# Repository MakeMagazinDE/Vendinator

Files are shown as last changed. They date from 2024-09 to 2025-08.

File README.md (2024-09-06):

GitHub Logo

Maker Media GmbH

***

# Verkaufsautomat mit ESP

### Eigene Waren zu vertreiben, kann ganz schön aufwendig sein. Mit einem selbst gebauten Automaten geht das ganz einfach. Einmal eingestellt, übernimmt er die Transaktionen und meldet Verkäufe und Fehler ans Smartphone. Man muss sich nur gut überlegen, wie Hard- und Software zusammenspielen sollen. Dann lässt sich sogar im Schlaf Geld verdienen.

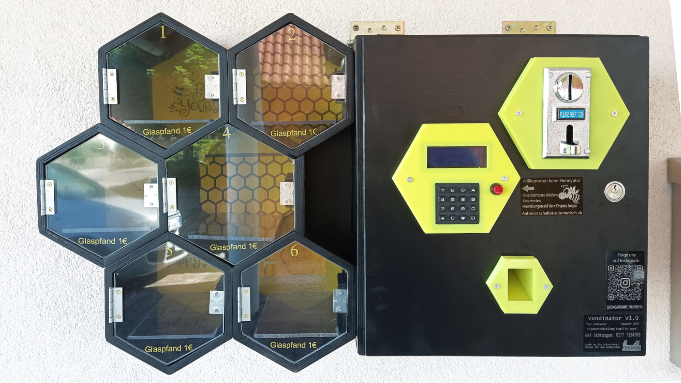
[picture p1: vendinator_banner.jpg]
Aufmacherbild aus dem Heft


Ergänzend zum Artikel in der Make 5/24 findet ihr hier die Sketches, Schaltpläne und Ablaufpläne.

Den vollständigen Artikel kann man in der **[Make-Ausgabe 5/24](https://www.heise.de/select/make/2024/5)** lesen.

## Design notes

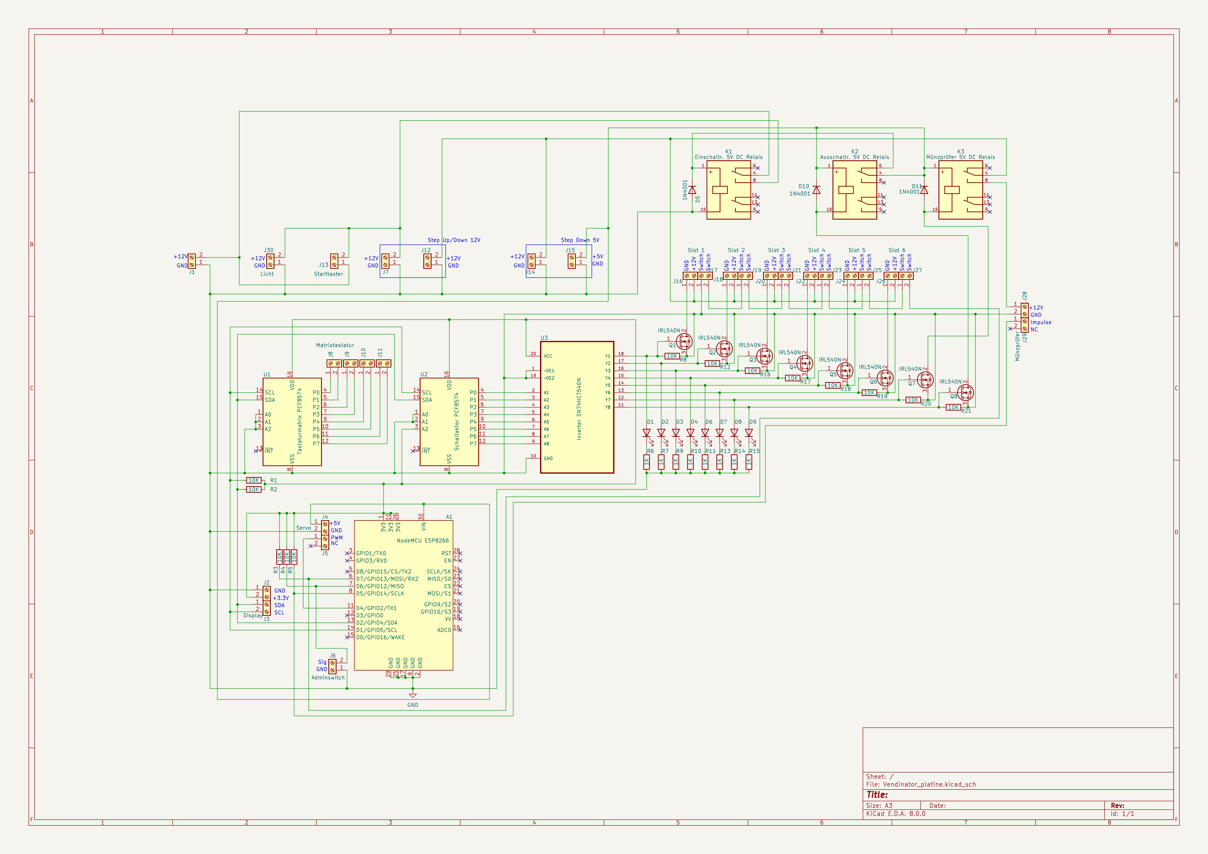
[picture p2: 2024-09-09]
Schaltplan/vendinator_schaltplan.jpg

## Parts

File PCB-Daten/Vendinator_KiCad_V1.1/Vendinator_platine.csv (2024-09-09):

# | Reference | Qty | Value | Footprint | DNP
1 | A1 | 1 | NodeMCU ESP8266 | Module:NodeMCU-LoLinV3
2 | D1 | 1 | LED grün | LED_THT:LED_D5.0mm
3 | D2, D3, D4, D5, D6, D7, D8 | 7 | LED | LED_THT:LED_D5.0mm
4 | D9, D10, D11 | 3 | 1N4001 | Diode_THT:D_DO-41_SOD81_P10.16mm_Horizontal
5 | J1 | 1 | Display | Connector_PinHeader_2.54mm:PinHeader_1x04_P2.54mm_Vertical
6 | J2 | 1 | Servo (Escrow) | Connector_PinSocket_2.54mm:PinSocket_1x03_P2.54mm_Vertical
7 | J3 | 1 | Adminswitch | Connector_Pin:Pin_D1.3mm_L11.0mm
8 | J4 | 1 | Matrixtastatur | Connector_PinSocket_2.54mm:PinSocket_1x08_P2.54mm_Vertical
9 | J5 | 1 | Münzprüfer | Connector_PinHeader_2.54mm:PinHeader_1x03_P2.54mm_Vertical
10 | J6 | 1 | Slot 1 | Connector_PinHeader_2.54mm:PinHeader_1x04_P2.54mm_Vertical
11 | J7 | 1 | Slot 2 | Connector_PinHeader_2.54mm:PinHeader_1x04_P2.54mm_Vertical
12 | J8 | 1 | Slot 3 | Connector_PinHeader_2.54mm:PinHeader_1x04_P2.54mm_Vertical
13 | J9 | 1 | Slot 4 | Connector_PinHeader_2.54mm:PinHeader_1x04_P2.54mm_Vertical
14 | J10 | 1 | Slot 5 | Connector_PinHeader_2.54mm:PinHeader_1x04_P2.54mm_Vertical
15 | J11 | 1 | Slot 6 | Connector_PinHeader_2.54mm:PinHeader_1x04_P2.54mm_Vertical
16 | J12 | 1 | Starttaster | Connector_PinHeader_2.54mm:PinHeader_1x02_P2.54mm_Vertical
17 | J13 | 1 | Batterie IN | Connector_PinHeader_2.54mm:PinHeader_1x02_P2.54mm_Vertical
18 | J14 | 1 | DC/DC 12V IN | Connector_PinHeader_2.54mm:PinHeader_1x02_P2.54mm_Vertical
19 | J15 | 1 | 12V DC/DC OUT | Connector_PinHeader_2.54mm:PinHeader_1x02_P2.54mm_Vertical
20 | J16 | 1 | 12V DC/DC IN | Connector_PinHeader_2.54mm:PinHeader_1x02_P2.54mm_Vertical
21 | J17 | 1 | 5V DC/DC OUT | Connector_PinHeader_2.54mm:PinHeader_1x02_P2.54mm_Vertical
22 | K1 | 1 | Münzprüfer 5V DC Relais | Relay_THT:Relay_DPDT_Finder_40.52
23 | K2 | 1 | Ausschaltr. 5V DC Relais | Relay_THT:Relay_DPDT_Finder_40.52
24 | K3 | 1 | Einschaltr. 5V DC Relais | Relay_THT:Relay_DPDT_Finder_40.52
25 | Q1, Q2, Q3, Q4, Q5, Q6, Q7, Q8 | 8 | IRL540N | Package_TO_SOT_THT:TO-220-3_Vertical
26 | R1, R2, R3, R4, R5, R6, R7, R8 | 8 | 1K | Resistor_THT:R_Axial_DIN0207_L6.3mm_D2.5mm_P10.16mm_Horizontal
27 | R9, R10, R11, R12, R13, R14, R15, R16, R17, R18, R19, R20, R21 | 13 | 10K | Resistor_THT:R_Axial_DIN0207_L6.3mm_D2.5mm_P10.16mm_Horizontal
28 | U1 | 1 | Tastaturmatrix PCF8574 | Package_DIP:DIP-16_W7.62mm_Socket_LongPads
29 | U2 | 1 | Schaltaktor PCF8574 | Package_DIP:DIP-16_W7.62mm_Socket_LongPads
30 | U3 | 1 | Inverter SN74HCT540N | Package_DIP:DIP-20_W7.62mm_Socket

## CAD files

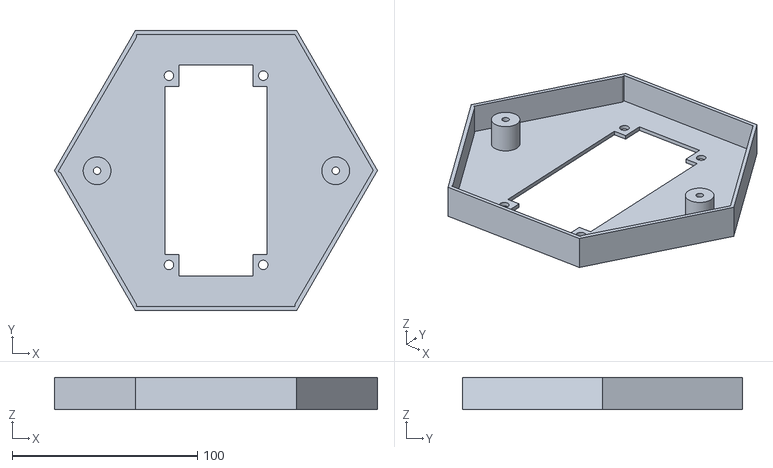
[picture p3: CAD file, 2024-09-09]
3D-Druckdaten/Wabe_Münzeinwurf.stl
174.5 x 151.1 x 17.5

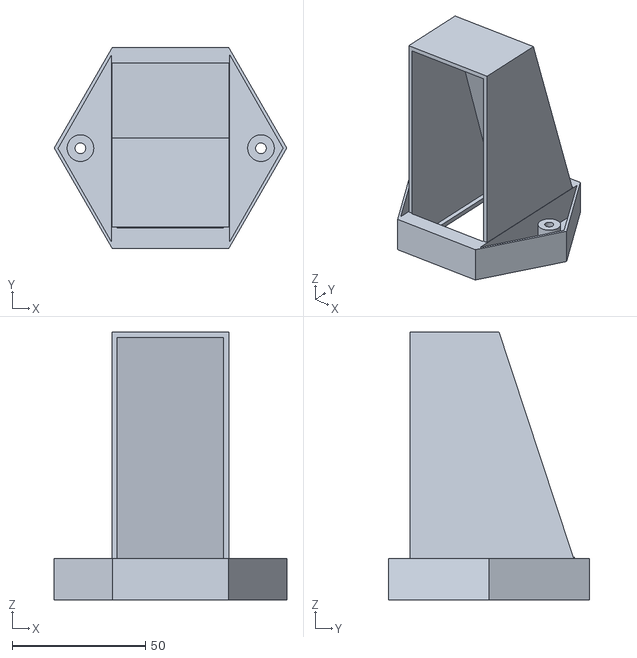
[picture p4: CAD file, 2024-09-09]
3D-Druckdaten/Geldrückgabe_Hauptteil.stl
87.2 x 75.6 x 100.5

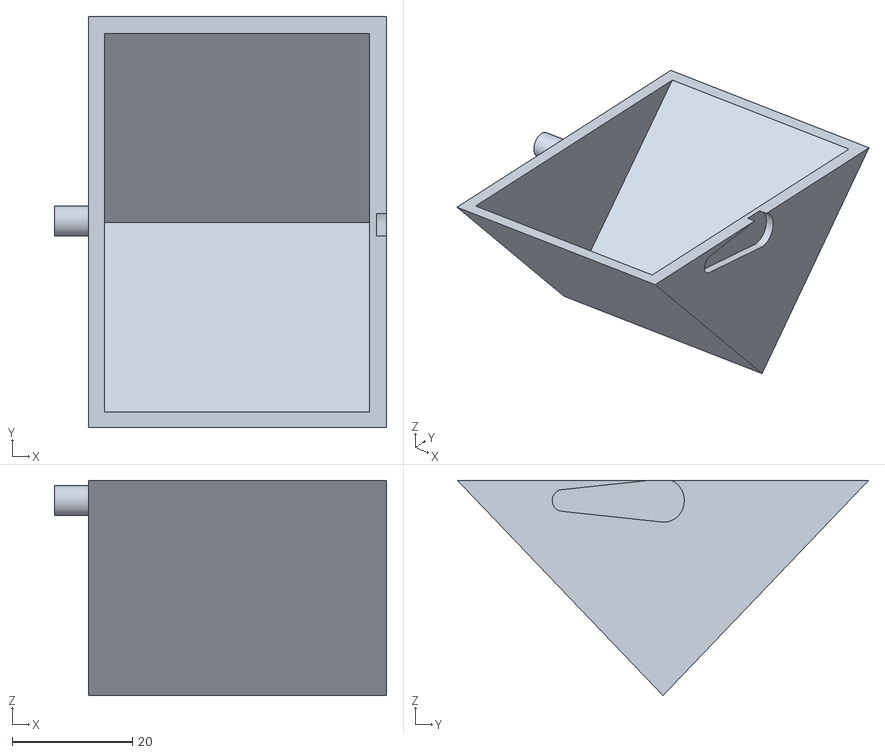
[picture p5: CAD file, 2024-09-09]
3D-Druckdaten/Münzweiche_Wippe.stl
55.3 x 68.5 x 35.9

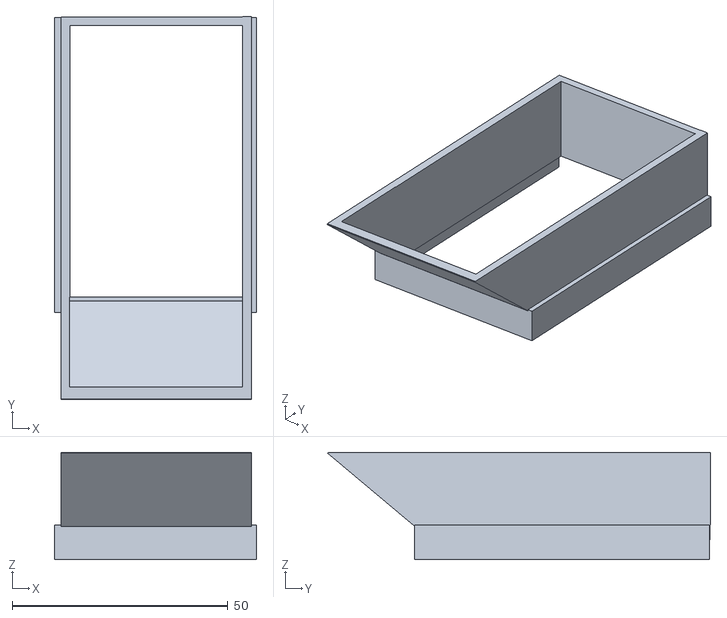
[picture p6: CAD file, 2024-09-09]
3D-Druckdaten/Geldrückgabe_Aufsatz.stl
46.8 x 88.7 x 24.8

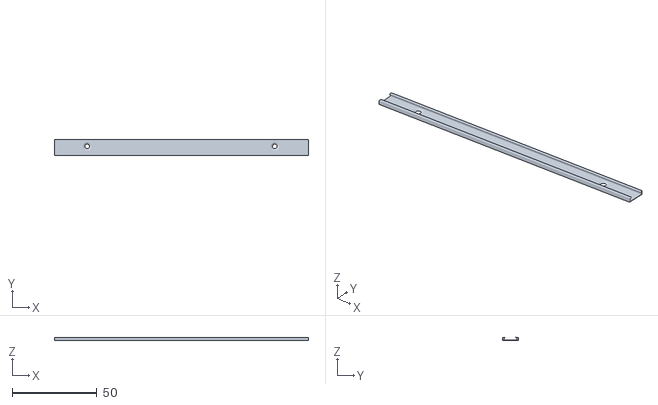
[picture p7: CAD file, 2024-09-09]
3D-Druckdaten/LEDStripe_Halter.stl
150.0 x 9.50 x 2.00

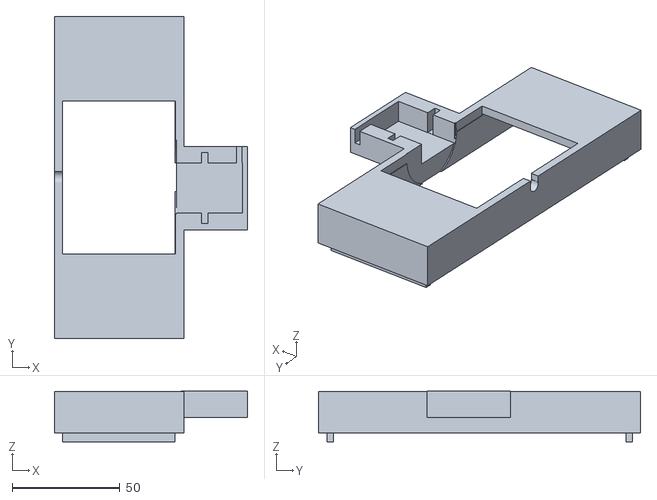
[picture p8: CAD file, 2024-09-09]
3D-Druckdaten/Münzweiche_Oberteil.stl
89.5 x 149.4 x 23.4

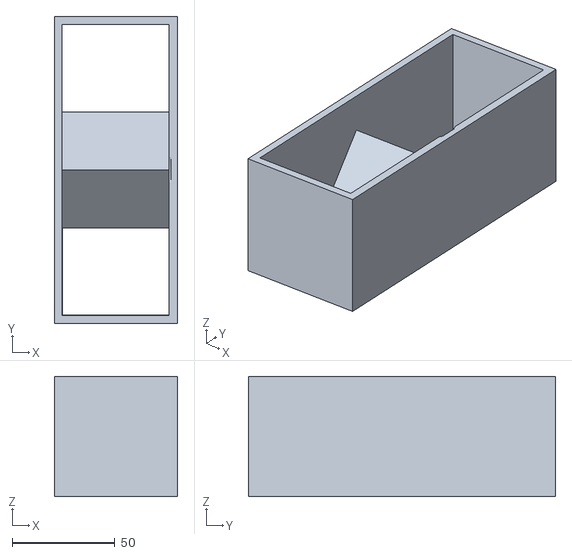
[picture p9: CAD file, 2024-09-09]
3D-Druckdaten/Münzweiche_Unterteil.stl
60.0 x 149.4 x 58.4

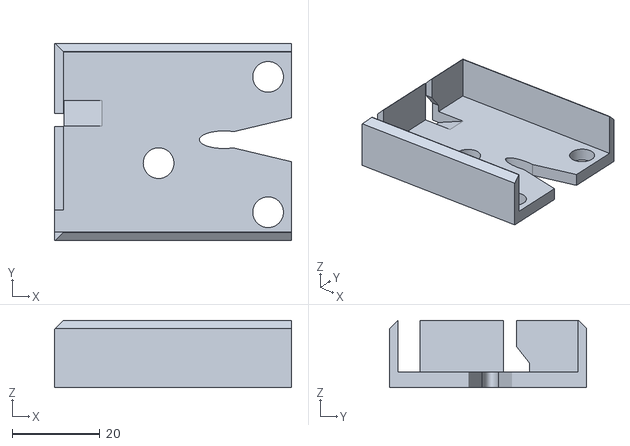
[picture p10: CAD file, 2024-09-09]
3D-Druckdaten/Schloss_Abstandshalter.stl
54.1 x 45.0 x 15.3

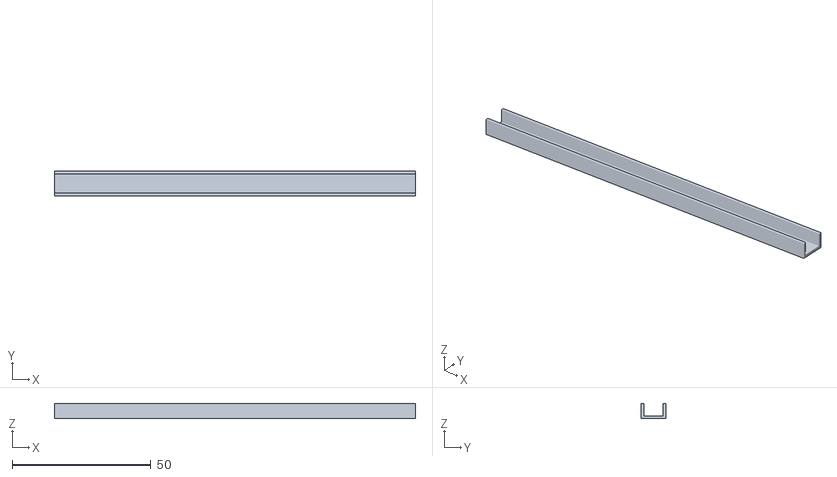
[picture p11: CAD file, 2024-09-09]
3D-Druckdaten/Kabelabdeckung.stl
130.0 x 9.00 x 5.50

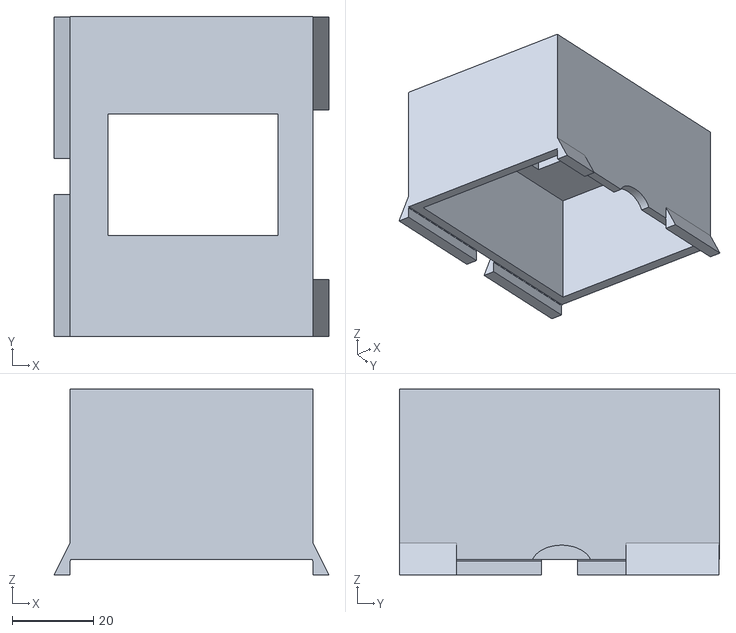
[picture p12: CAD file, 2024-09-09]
3D-Druckdaten/Münzweiche_Aufsatz.stl
67.8 x 79.0 x 45.8

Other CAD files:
3D-Druckdaten/Wabe_Bedienteil.stl

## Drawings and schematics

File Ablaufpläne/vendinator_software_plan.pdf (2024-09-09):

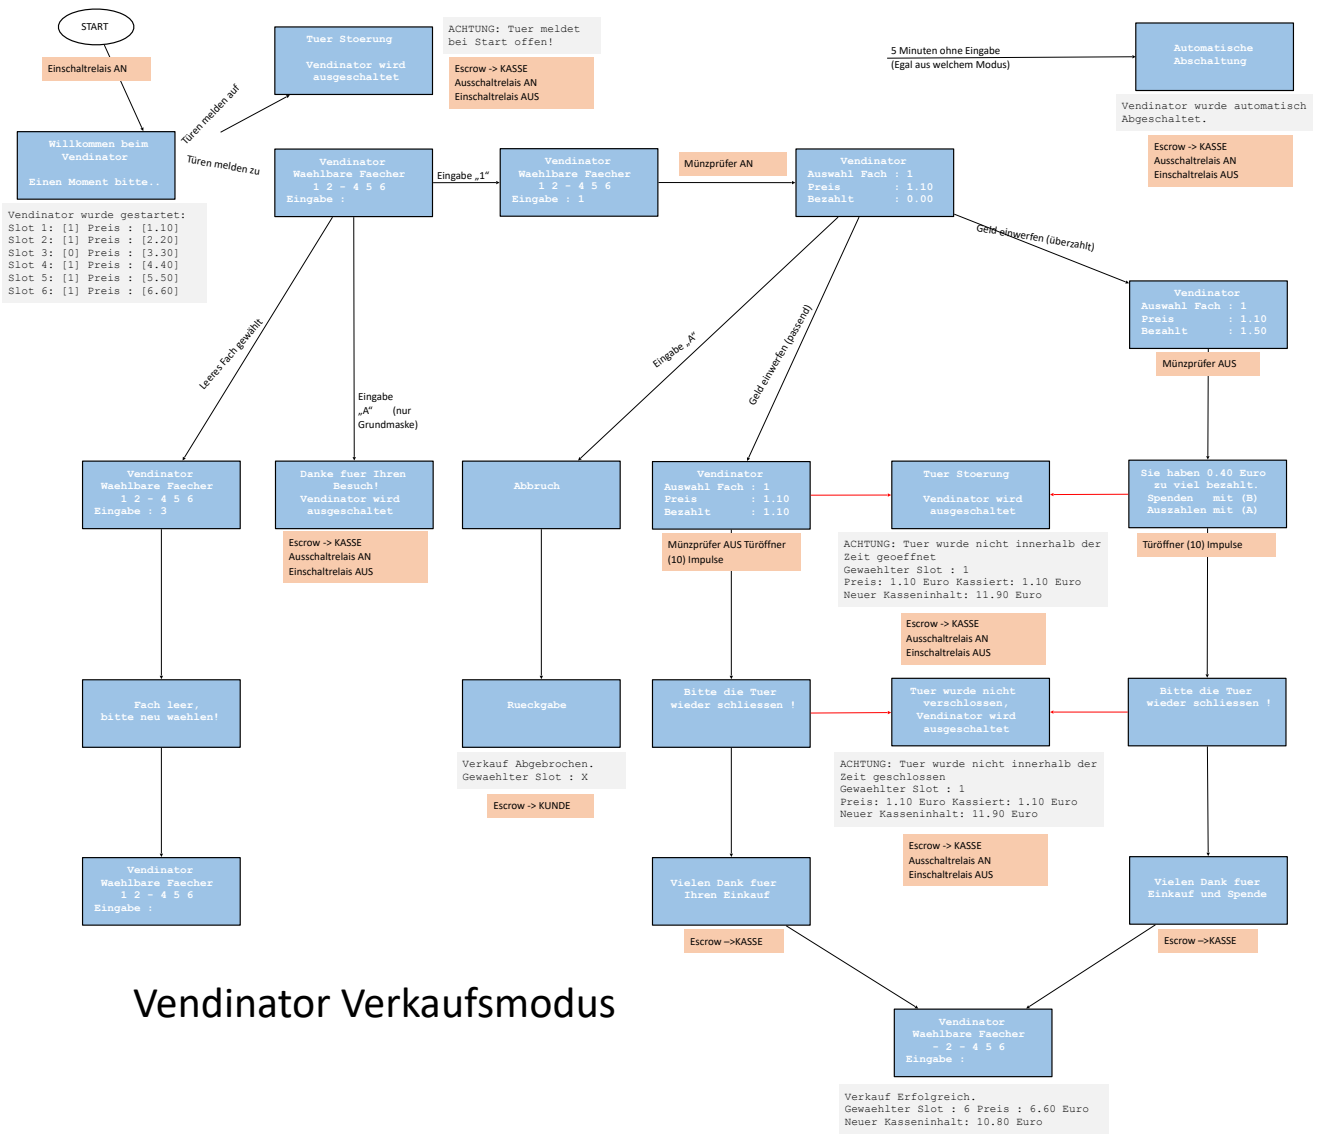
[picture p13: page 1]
Vendinator Waehlbare Faecher 1 2 - 4 5 6 Eingabe :; Vendinator Waehlbare Faecher 1 2 - 4 5 6 Eingabe : 1; Vendinator Auswahl Fach : 1; Preis; Bezahlt; Abbruch; Tuer Stoerung; Vendinator wird ausgeschaltet; Vendinator Waehlbare Faecher - 2 - 4 5 6 Eingabe :; Spenden; mit (B); Vendinator Verkaufsmodus; Willkommen beim Vendinator; START; Eingabe „1“; Eingabe „A“; Vendinator Waehlbare Faecher 1 2 - 4 5 6 Eingabe : 3; Eingabe; (nur; Grundmaske); Rueckgabe; Verkauf Abgebrochen. Gewaehlter Slot : X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

ACHTUNG: Tuer meldet
bei Start offen!

5 Minuten ohne Eingabe
(Egal aus welchem Modus)

Türen melden auf

Vendinator wurde automatisch
Abgeschaltet.

Türen melden zu

Einen Moment bitte..

Vendinator wurde gestartet:
Slot 1: [1] Preis : [1.10]
Slot 2: [1] Preis : [2.20]
Slot 3: [0] Preis : [3.30]
Slot 4: [1] Preis : [4.40]
Slot 5: [1] Preis : [5.50]
Slot 6: [1] Preis : [6.60]

Geld einwerfen (überzahlt)

Geld einwerfen (passend)

Leeres Fach gewählt

Danke fuer Ihren
Besuch!
Vendinator wird
ausgeschaltet

Sie haben 0.40 Euro
zu viel bezahlt.
Auszahlen mit (A)

ACHTUNG: Tuer wurde nicht innerhalb der
Zeit geoeffnet
Gewaehlter Slot : 1
Preis: 1.10 Euro Kassiert: 1.10 Euro
Neuer Kasseninhalt: 11.90 Euro

Münzprüfer AUS Türöffner
(10) Impulse

Bitte die Tuer
wieder schliessen !

Tuer wurde nicht
verschlossen,

Fach leer,
bitte neu waehlen!

Zeit geschlossen

Vielen Dank fuer
Ihren Einkauf

Einkauf und Spende

Verkauf Erfolgreich.
Gewaehlter Slot : 6 Preis : 6.60 Euro
Neuer Kasseninhalt: 10.80 Euro

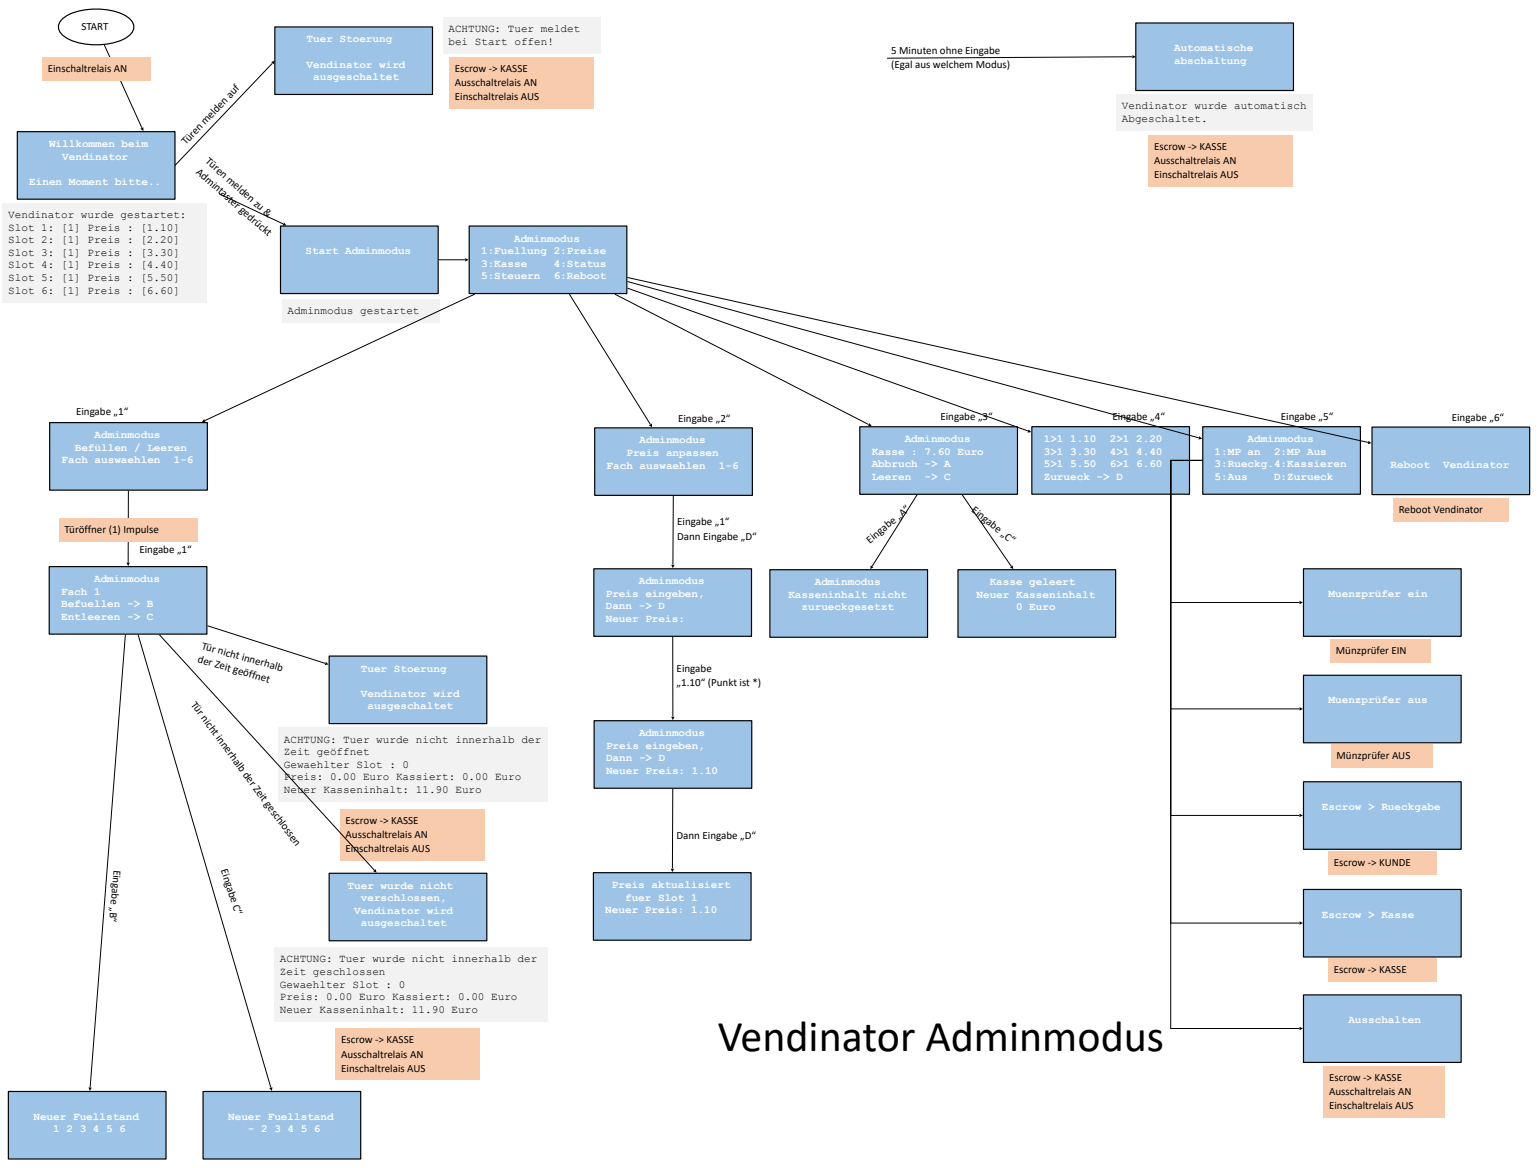
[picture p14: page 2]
Adminmodus 1:Fuellung 2:Preise; 3:Kasse; 4:Status; 5:Steuern 6:Reboot; Adminmodus Befüllen / Leeren Fach auswaehlen 1-6; Adminmodus Fach 1 Befuellen -> B Entleeren -> C; Adminmodus Preis anpassen Fach auswaehlen 1-6; Adminmodus Preis eingeben, Dann -> D Neuer Preis:; Adminmodus Preis eingeben, Dann -> D Neuer Preis: 1.10; Preis aktualisiert fuer Slot 1 Neuer Preis: 1.10; Adminmodus Kasse : 7.60 Euro Abbruch -> A Leeren -> C; Adminmodus Kasseninhalt nicht zurueckgesetzt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

ACHTUNG: Tuer meldet
bei Start offen!

5 Minuten ohne Eingabe
(Egal aus welchem Modus)

Türen melden auf

Vendinator wurde automatisch
Abgeschaltet.

Türen melden zu &

Einen Moment bitte..

Vendinator wurde gestartet:
Slot 1: [1] Preis : [1.10]
Slot 2: [1] Preis : [2.20]
Slot 3: [1] Preis : [3.30]
Slot 4: [1] Preis : [4.40]
Slot 5: [1] Preis : [5.50]
Slot 6: [1] Preis : [6.60]

Adminmodus
1:MP an 2:MP Aus
3:Rueckg.4:Kassieren

Eingabe „1“ Dann Eingabe „D“ | Reboot Vendinator

Türöffner (1) Impulse

Tür nicht innerhalb

der Zeit geöffnet

Tür nicht innerhalb der Zeit geschlossen

ACHTUNG: Tuer wurde nicht innerhalb der
Zeit geöffnet
Gewaehlter Slot : 0
Preis: 0.00 Euro Kassiert: 0.00 Euro
Neuer Kasseninhalt: 11.90 Euro

Tuer wurde nicht
verschlossen,
Vendinator wird
ausgeschaltet

Zeit geschlossen

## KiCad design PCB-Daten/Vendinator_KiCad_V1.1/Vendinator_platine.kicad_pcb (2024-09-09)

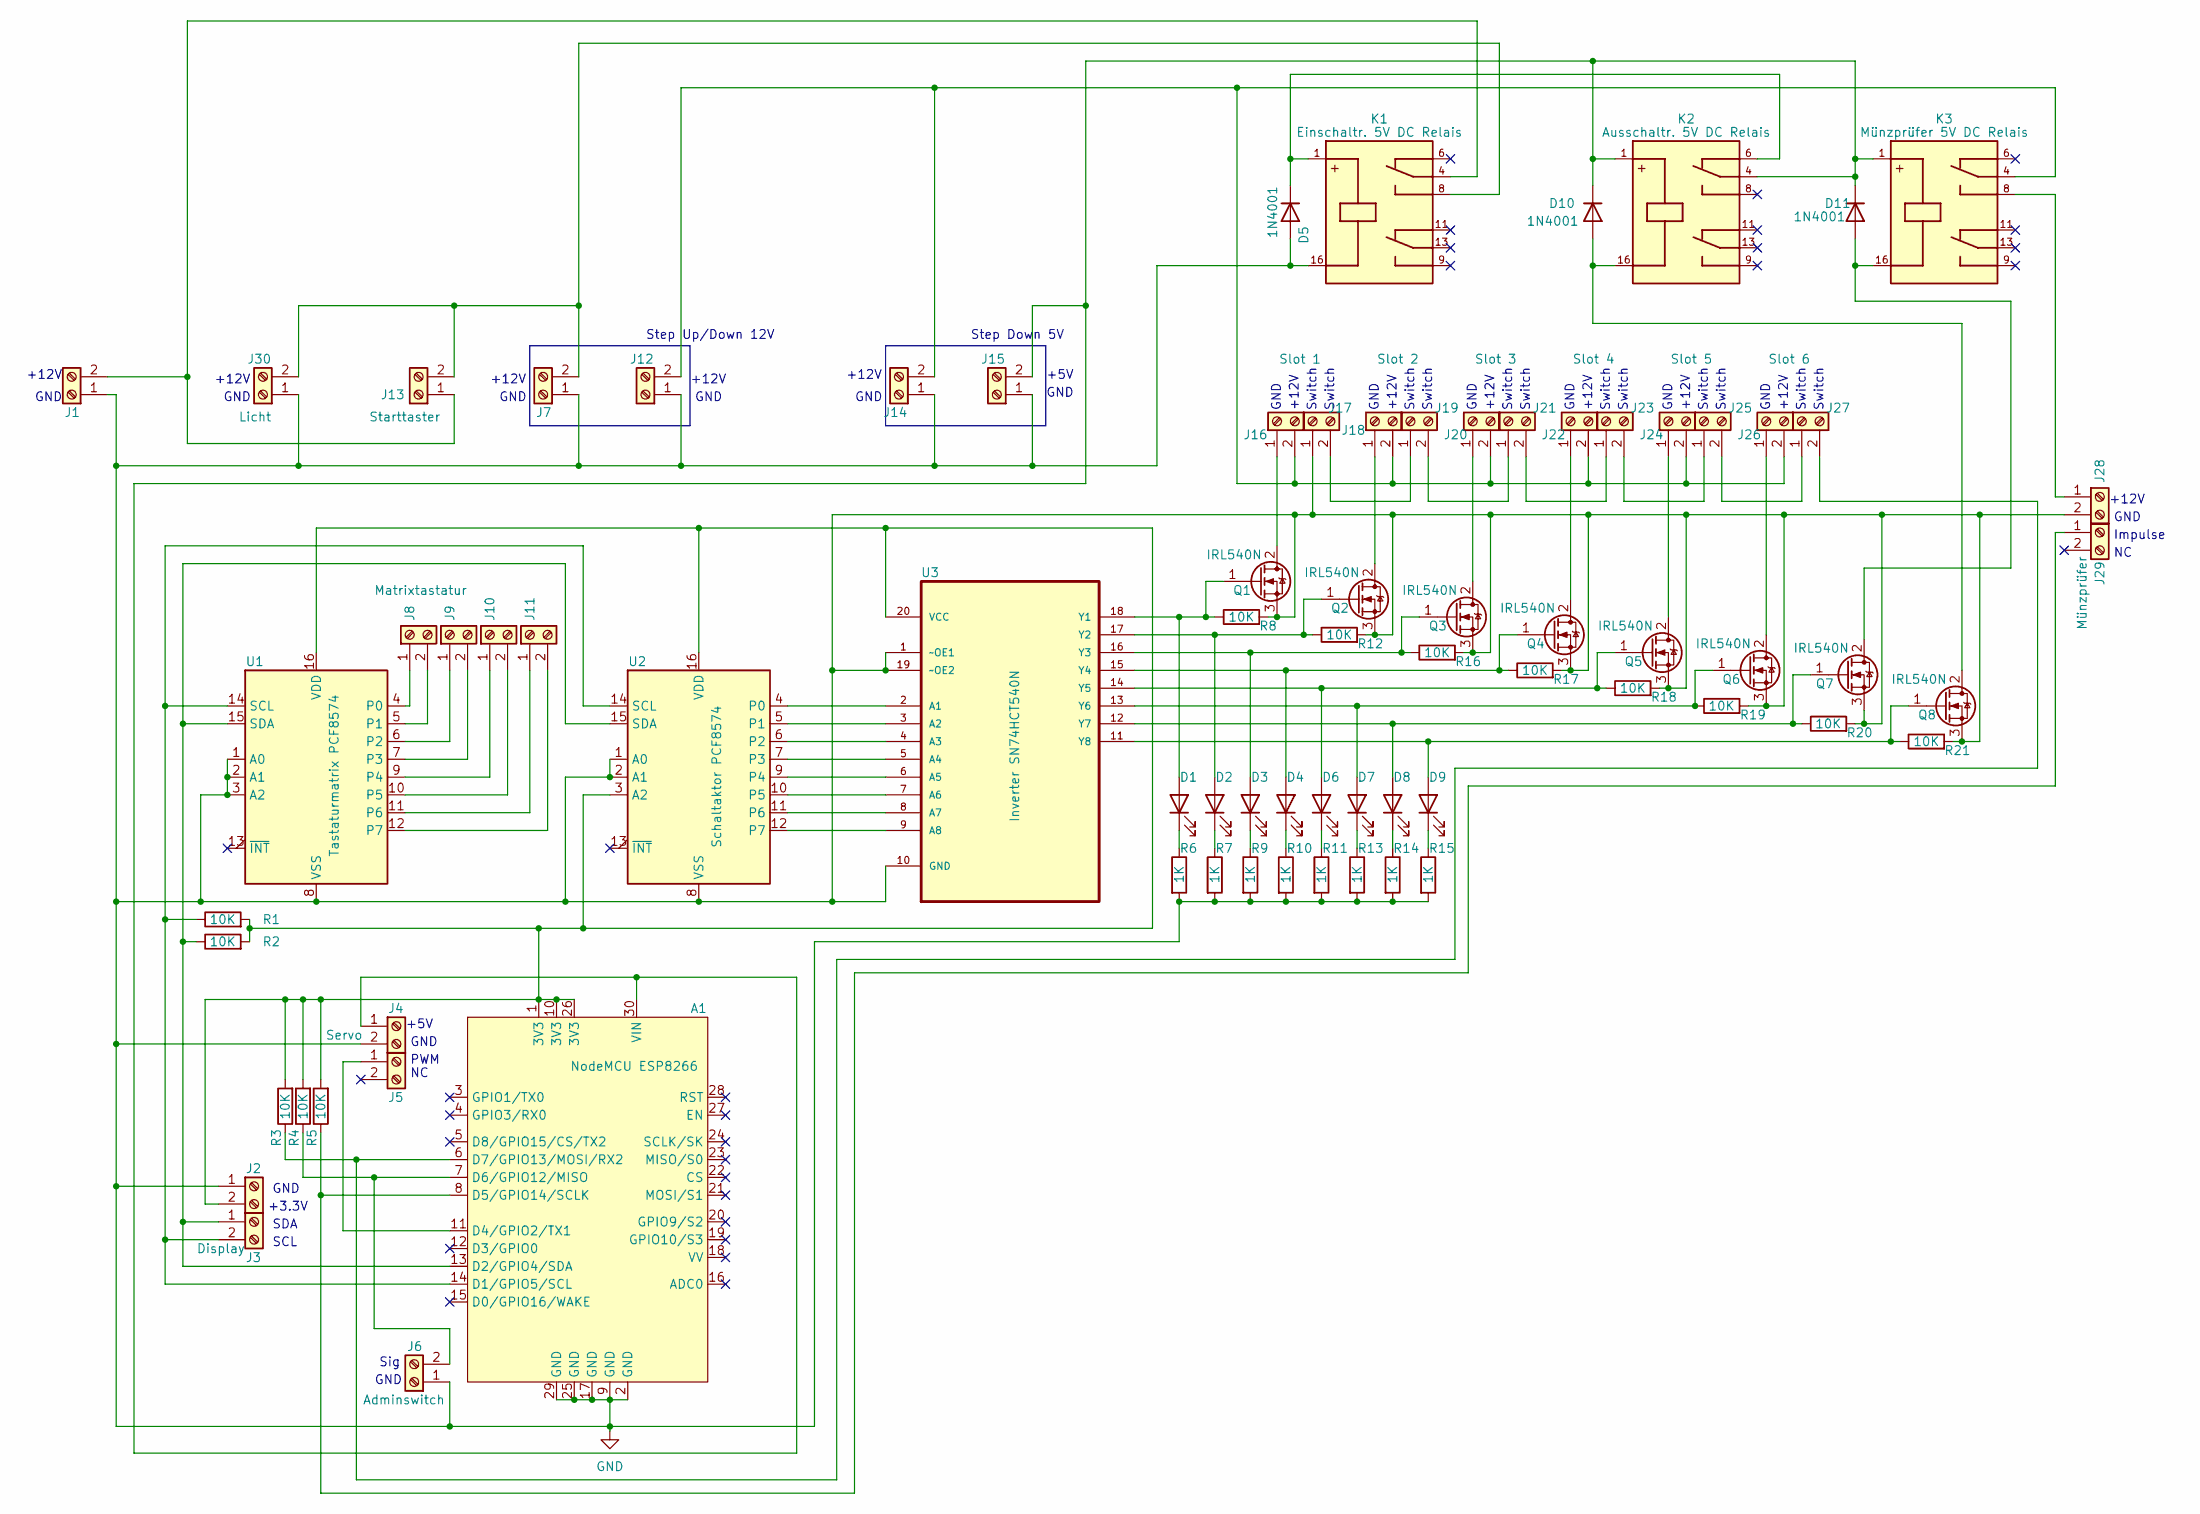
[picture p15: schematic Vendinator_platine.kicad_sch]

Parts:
A1: NodeMCU ESP8266; NodeMCU-LoLinV3_2
D1: LED grün; LED_D5.0mm
D2, D3, D4, D6, D7, D8, D9: LED; LED_D5.0mm
D5, D10, D11: 1N4001; D_DO-41_SOD81_P10.16mm_Horizontal
J1: Batterie IN; TerminalBlock_MetzConnect_Type011_RT05502HBWC_1x02_P5.00mm_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
J2: Display; TerminalBlock_MetzConnect_Type011_RT05502HBWC_1x02_P5.00mm_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
J3: Display 2; TerminalBlock_MetzConnect_Type011_RT05502HBWC_1x02_P5.00mm_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
J4: Servo; TerminalBlock_MetzConnect_Type011_RT05502HBWC_1x02_P5.00mm_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
J5: Servo 2; TerminalBlock_MetzConnect_Type011_RT05502HBWC_1x02_P5.00mm_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
J6: Adminswitch; TerminalBlock_MetzConnect_Type011_RT05502HBWC_1x02_P5.00mm_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
J7: 12V Step Up/Down IN; JUP_P20mm
J8: Matrixtastatur; TerminalBlock_MetzConnect_Type011_RT05502HBWC_1x02_P5.00mm_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
J9: Matrixtastatur 2; TerminalBlock_MetzConnect_Type011_RT05502HBWC_1x02_P5.00mm_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
J10: Matrixtastatur 3; TerminalBlock_MetzConnect_Type011_RT05502HBWC_1x02_P5.00mm_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
J11: Matrixtastatur 4; TerminalBlock_MetzConnect_Type011_RT05502HBWC_1x02_P5.00mm_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
J12: 12V Step Up/Down OUT; JUP_P20mm
J13: Starttaster; TerminalBlock_MetzConnect_Type011_RT05502HBWC_1x02_P5.00mm_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
J14: Step Down 5V IN; JUP_P20mm
J15: Step Down 5V OUT; JUP_P20mm
J16: Slot 1; TerminalBlock_MetzConnect_Type011_RT05502HBWC_1x02_P5.00mm_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
J17: Slotswitch 1; TerminalBlock_MetzConnect_Type011_RT05502HBWC_1x02_P5.00mm_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
J18: Slot 2; TerminalBlock_MetzConnect_Type011_RT05502HBWC_1x02_P5.00mm_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
J19: Slotswitch 2; TerminalBlock_MetzConnect_Type011_RT05502HBWC_1x02_P5.00mm_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
J20: Slot 3; TerminalBlock_MetzConnect_Type011_RT05502HBWC_1x02_P5.00mm_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
J21: Slotswitch 3; TerminalBlock_MetzConnect_Type011_RT05502HBWC_1x02_P5.00mm_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
J22: Slot 4; TerminalBlock_MetzConnect_Type011_RT05502HBWC_1x02_P5.00mm_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
J23: Slotswitch 4; TerminalBlock_MetzConnect_Type011_RT05502HBWC_1x02_P5.00mm_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
J24: Slot 5; TerminalBlock_MetzConnect_Type011_RT05502HBWC_1x02_P5.00mm_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
J25: Slotswitch 5; TerminalBlock_MetzConnect_Type011_RT05502HBWC_1x02_P5.00mm_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
J26: Slot 6; TerminalBlock_MetzConnect_Type011_RT05502HBWC_1x02_P5.00mm_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
J27: Slotswitch 6; TerminalBlock_MetzConnect_Type011_RT05502HBWC_1x02_P5.00mm_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
J28: Münzprüfer; TerminalBlock_MetzConnect_Type011_RT05502HBWC_1x02_P5.00mm_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
J29: Münzprüfer 2; TerminalBlock_MetzConnect_Type011_RT05502HBWC_1x02_P5.00mm_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
J30: Licht; TerminalBlock_MetzConnect_Type011_RT05502HBWC_1x02_P5.00mm_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
K1: Einschaltr. 5V DC Relais; SDS_Relay; PARTREV 0917
K2: Ausschaltr. 5V DC Relais; SDS_Relay; PARTREV 0917
K3: Münzprüfer 5V DC Relais; SDS_Relay; PARTREV 0917
Q1, Q2, Q3, Q4, Q5, Q6, Q7, Q8: IRL540N; TO-220-3_Vertical
R1, R2, R3, R4, R5, R8, R12, R16, R17, R18, R19, R20, R21: 10K; R_Axial_DIN0207_L6.3mm_D2.5mm_P10.16mm_Horizontal
R6, R7, R9, R10, R11, R13, R14, R15: 1K; R_Axial_DIN0207_L6.3mm_D2.5mm_P10.16mm_Horizontal
U1: Tastaturmatrix PCF8574; DIP-16_W7.62mm_Socket_LongPads
U2: Schaltaktor PCF8574; DIP-16_W7.62mm_Socket_LongPads
U3: Inverter SN74HCT540N; DIP-20_W7.62mm_Socket_LongPads; MPN SN74HCT540N

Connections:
GND: A1.2 (GND), A1.9 (GND), A1.17 (GND), A1.25 (GND), A1.29 (GND), D5.2 (A), J1.1, J2.1, J4.2, J6.1, J7.1, J12.1, J14.1, J15.1, J17.1, J28.2, J30.1, K1.16, Q1.3 (S), Q2.3 (S), Q3.3 (S), Q4.3 (S), Q5.3 (S), Q6.3 (S), Q7.3 (S), Q8.3 (S), R6.2, R7.2, R8.2, R9.2, R10.2, R11.2, R12.2, R13.2, R14.2, R15.2, R16.2, R17.2, R18.2, R19.2, R20.2, R21.2, U1.1 (A0), U1.2 (A1), U1.3 (A2), U1.8 (VSS), U2.1 (A0), U2.2 (A1), U2.8 (VSS), U3.1 (~OE1), U3.10 (GND), U3.19 (~OE2)
unnamed: A1.14 (D1/GPIO5/SCL), J3.2, R1.1, U1.14 (SCL), U2.14 (SCL)
unnamed: A1.13 (D2/GPIO4/SDA), J3.1, R2.1, U1.15 (SDA), U2.15 (SDA)
unnamed: A1.11 (D4/GPIO2/TX1), J5.1
unnamed: A1.8 (D5/GPIO14/SCLK), J29.1, R5.1
unnamed: A1.7 (D6/GPIO12/MISO), J6.2, R4.1
unnamed: A1.6 (D7/GPIO13/MOSI/RX2), J27.2, R3.1
unnamed: A1.30 (VIN), D10.1 (K), D11.1 (K), J4.1, J15.2, K2.1, K2.4, K3.1
unnamed: D1.2 (A), Q1.1 (G), R8.1, U3.18 (Y1)
unnamed: D1.1 (K), R6.1
unnamed: D2.2 (A), Q2.1 (G), R12.1, U3.17 (Y2)
unnamed: D2.1 (K), R7.1
unnamed: D3.2 (A), Q3.1 (G), R16.1, U3.16 (Y3)
unnamed: D3.1 (K), R9.1
unnamed: D4.2 (A), Q4.1 (G), R17.1, U3.15 (Y4)
unnamed: D4.1 (K), R10.1
unnamed: D5.1 (K), K1.1, K2.6
unnamed: D6.2 (A), Q5.1 (G), R18.1, U3.14 (Y5)
unnamed: D6.1 (K), R11.1
unnamed: D7.2 (A), Q6.1 (G), R19.1, U3.13 (Y6)
unnamed: D7.1 (K), R13.1
unnamed: D8.2 (A), Q7.1 (G), R20.1, U3.12 (Y7)
unnamed: D8.1 (K), R14.1
unnamed: D9.2 (A), Q8.1 (G), R21.1, U3.11 (Y8)
unnamed: D9.1 (K), R15.1
unnamed: D10.2 (A), K2.16, Q8.2 (D)
unnamed: D11.2 (A), K3.16, Q7.2 (D)
unnamed: J1.2, J13.1, K1.4
unnamed: A1.1 (3V3), A1.10 (3V3), A1.26 (3V3), J2.2, R1.2, R2.2, R3.2, R4.2, R5.2, U1.16 (VDD), U2.3 (A2), U2.16 (VDD), U3.20 (VCC)
unnamed: J8.1, U1.4 (P0)
unnamed: J8.2, U1.5 (P1)
unnamed: J9.1, U1.6 (P2)
unnamed: J9.2, U1.7 (P3)
unnamed: J10.1, U1.9 (P4)
unnamed: J10.2, U1.10 (P5)
unnamed: J11.1, U1.11 (P6)
unnamed: J11.2, U1.12 (P7)
unnamed: J12.2, J14.2, J16.2, J18.2, J20.2, J22.2, J24.2, J26.2, K3.4
unnamed: J7.2, J13.2, J30.2, K1.8
unnamed: J16.1, Q1.2 (D)
unnamed: J17.2, J19.1
unnamed: J18.1, Q2.2 (D)
unnamed: J19.2, J21.1
unnamed: J20.1, Q3.2 (D)
unnamed: J21.2, J23.1
unnamed: J22.1, Q4.2 (D)
unnamed: J23.2, J25.1
unnamed: J24.1, Q5.2 (D)
unnamed: J25.2, J27.1
unnamed: J26.1, Q6.2 (D)
unnamed: J28.1, K3.8
unnamed: U2.4 (P0), U3.2 (A1)
unnamed: U2.5 (P1), U3.3 (A2)
unnamed: U2.6 (P2), U3.4 (A3)
unnamed: U2.7 (P3), U3.5 (A4)
unnamed: U2.9 (P4), U3.6 (A5)
unnamed: U2.10 (P5), U3.7 (A6)
unnamed: U2.11 (P6), U3.8 (A7)
unnamed: U2.12 (P7), U3.9 (A8)

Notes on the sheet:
Switch
Impulse
GND
+5V
+12V
+12V
SCL
SDA
+3.3V
Step Down 5V
GND
PWM
Sig
Step Up/Down 12V

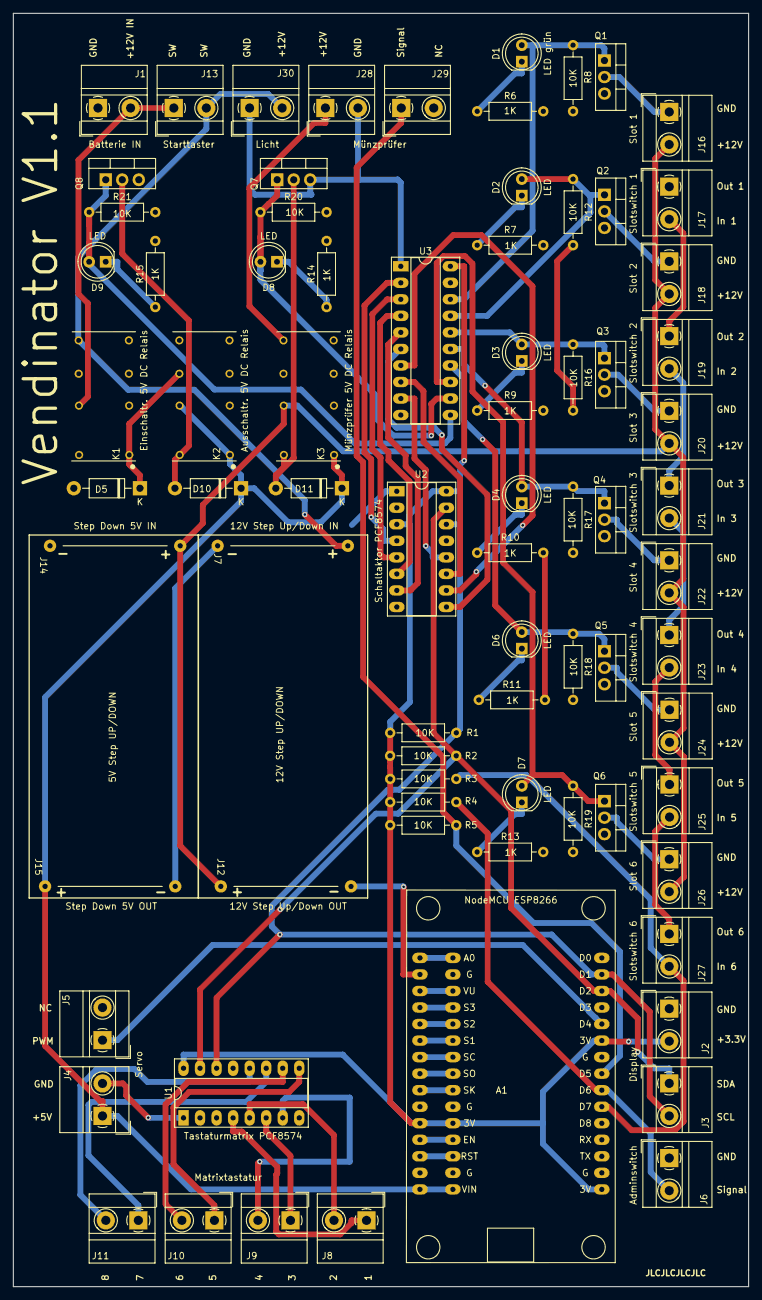
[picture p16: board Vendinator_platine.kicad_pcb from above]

Board: 2 copper layers, 113.0 x 195.6 mm, 77 parts (0 on the bottom side), 59 nets.

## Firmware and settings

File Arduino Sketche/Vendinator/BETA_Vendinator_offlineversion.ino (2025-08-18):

/* VENDINATOR
  Display (I²C)                                                                                     : https://github.com/johnrickman/LiquidCrystal_I2C
  PCF8574 (I²C)          -> Tastaturmatrix                                                          : https://github.com/joeyoung/arduino_keypads
  PCF8574 (I²C)          -> Türmagnete ->Stromversorgung Münzprüfer ->Stromversorogung Automat      : Wire.h (Standard Bibliothek für I²C)
  Servo                  -> Münzweiche (Escrow)                                                     : Servo.h (Standard Bibliothek für I²C)
  EEprom                 -> EEProm als nichtflüchtigen Speicher für Preise/Inhalt usw.              : https://github.com/esp8266/Arduino/blob/master/libraries/EEPROM/EEPROM.h
  ESP8266WiFi.h          -> Wlan Funktionalität den ESP8266 (Für Telegramm)                         : https://github.com/esp8266/Arduino/tree/master/libraries/ESP8266WiFi
  WiFiClientSecure.h     -> Für gesicherte Websiten. (Für Telegramm)                                : github.com/esp8266/Arduino/blob/master/libraries/ESP8266WiFi
  UniversalTelegramBot.h -> Telegrammnachrichten versenden                                          : https://github.com/witnessmenow/Universal-Arduino-Telegram-Bot

  History
  01.07.2023 Keypad und Display zusammen
  09.10.2023 Münzweiche mit Funktionen hinzugefügt | IOExpander mit Funktionen hinzugefügt
  11.10.2023 Code für Münzprüfer hinzugefügt
  21.10.2023 EEPROM hinzugefügt
  27.10.2023 Funktionen hinzugefügt (updateInventory, Printslots...)
  09.11.2023 Adminmodus fertiggestellt, Tringgeld funktion, Idle Timer
  13.11.2023 Funktionierende Version mit Verkauf in Spagetti-Code :-)
  16.11.2023 Verkauf in Zustandsmaschine umgebaut. - Alle Funktionenen (Ohne Onlinefunktionalität) Test i.O.
  16.11.2023 Telegramm Statusmeldungen
  20.11.2023 Funktion openslot erneuert.
  20.11.2023 Version 1.0
  18.01.2024 Openslot: Abschaltung bei Störung / Tür Überprüfung bei Start / Auschalten im Verkauf durch Kunde möglich
  16.06.2024 Text bei überzahlung angepasst, Zeiten angepasst, Text bei Türstörung erweitert

  15.05.2025 Offlineversion erstellt
  
*/
//#include <ESP8266WiFi.h>                                                                            // WiFi Bibliothek für ESP8266
//#include <WiFiClientSecure.h>                                                                       // Bibliothek um gesicherte Websiten aufrufen zu können 
#include <LiquidCrystal_I2C.h>                                                                      // I2C LCD_Display
#include <Keypad_I2C.h>                                                                             // I2C Tastaturmatrix an PCF8574 
#include <Keypad.h>                                                                                 // Passende Datei für 4x4 Matrix Keypad
#include <Wire.h>                                                                                   // Standart Bibliothek für I²C 
#include <Servo.h>                                                                                  // Standart Servo Bibliothek für Münzweiche (Escrow)
#include <EEPROM.h>                                                                                 // EEPROM Bibliothek

//#include <UniversalTelegramBot.h>                                                                   // UniversalTelegramBot.h

Servo escrow;
#define IOexpander (0x3C)                                                                           // I2C Slave Addresse des PCF 8574 für Türen und andere Schaltaufgaben
#define I2CADDR 0x38                                                                                // Adresse PCF8574 für das Keypad
const byte ROWS = 4;                                                                                // 4 Reihen
const byte COLS = 4;                                                                                // 4 Spalten

#define EEPROM_SIZE 512                                                                             // EEPROM größe festlegen

//#define WIFI_SSID "WLAN Name"                                                                     // WLAN-Netzwerkstation-Daten
//#define WIFI_PASSWORD "ABCDEFG1234567HIJKLMNOP89012"                                              // WLAN Passwort
//#define BOT_TOKEN "1234567890:ABCDEFG-HIJKLMNOPQRSTUVWXYZabcdefgh"                                // Telegram BOT-Token (Vom Botfather erhalten)
//#define CHAT_ID "12345678905"                                                                     // Chat-ID, an die die Statusmeldung gesendet werden soll

//X509List cert(TELEGRAM_CERTIFICATE_ROOT);                                                           // Verschiedenes für Telegramm Bot
//WiFiClientSecure secured_client;
//UniversalTelegramBot bot(BOT_TOKEN, secured_client);

char hexaKeys[ROWS][COLS] = {                                                                       // Tasten der Tastatur definieren
  {'D', '#', '0', '*'},
  {'C', '9', '8', '7'},
  {'B', '6', '5', '4'},
  {'A', '3', '2', '1'}
};

byte rowPins[ROWS] = {0, 1, 2, 3};                                                                  // Tastaturmatrix Anschluss der Reihen
byte colPins[COLS] = {4, 5, 6, 7};                                                                  // Tastaturmatrix Anschluss der Spalten

Keypad_I2C customKeypad( makeKeymap(hexaKeys), rowPins, colPins, ROWS, COLS, I2CADDR);              // Keypad initialisieren

int lcdColumns = 20;                                                                                // LCD Display Spalten
int lcdRows = 4;                                                                                    // LCD Display Reihen

LiquidCrystal_I2C lcd(0x27, lcdColumns, lcdRows);                                                   // LCD I2C Adresse, Spalten und Reihen

int timeout = 715;                                                                                  // So lange werden die Impulse gezählt
int timenow;                                                                                        // Zeitvariable jetzt
float credit = 0;                                                                                   // Hier wird das Eingeworfene Geld summiert
float cost = 0;                                                                                     // Der Preis des Produktes für Bezahlfunktion
int coinimpulse = 0;                                                                                // Impulse des Münzprüfers

//String statusMessage;                                                                               // Meldungsstring für Telegramm

bool coinnew = false;                                                                               // Wird "true" wenn neue Münze eingeworfen

unsigned long coinstart = 0;                                                                        // Zeitstop neue Münze Start
unsigned long cointimeout = 0;                                                                      // Neue Münze start + timeout

static const uint8_t  coinpin = D5;                                                                 // Pin für die Impulse des Münzprüfers
static const uint8_t  adminpin = D6;                                                                // Pin für den Adminzugang
static const uint8_t  lockpin = D7;                                                                 // Pin für den Schlosskontakt

int choice = 0;                                                                                     // Getroffene Auswahl (Hilfsvariable)
int adminstate = 0;                                                                                 // Status im Adminmenü
int vendingstate = 0;                                                                               // Status im Verkaufsmenu
int doorstate = 0;                                                                                  // Türstatus (Normal = Tür zu = 0)
String priceStr = "";                                                                               // Zeichenkette zur Eingabe des Preises

int priceAdjustSlot = 0;                                                                            // Preiseingabe Hilfsvariable

int slotNum = 0;                                                                                    // Hilfsvariable Slot im

bool slot_1 = 0;                                                                                    // Variablen für Fächerinhalt ja/nein
bool slot_2 = 0;
bool slot_3 = 0;
bool slot_4 = 0;
bool slot_5 = 0;
bool slot_6 = 0;

float cost_1 = 99.99;                                                                               // Variablen für Preise
float cost_2 = 99.99;
float cost_3 = 99.99;
float cost_4 = 99.99;
float cost_5 = 99.99;
float cost_6 = 99.99;

float cash = 00.00;                                                                                 // Variablen für Kasseninhalt

int maxRetries = 10;                                                                                // Versuche die Tür zu öffnen
unsigned long previousMillis = 0;                                                                   // Start Idle Timer für automatische Abschaltung
const long maxtidle = 300000;                                                                       // 5 Minuten maximale Zeit

unsigned long currentMillis;                                                                        // Variable für JETZT

void ICACHE_RAM_ATTR isr() {                                                                        // Interrupt funktion für die Münzprüfer Impulse
  timenow = millis();
  if (coinnew == false) {
    coinnew = true;
    coinstart = millis();
    cointimeout = coinstart + timeout;
  }
  if (coinnew == true && timenow < cointimeout) {
    timenow = millis();
    coinimpulse++;
  }
}

//------------------------------------------------> BEGINN FUNKTIONEN

void refund() {                                                                                     // Münzrückgabe
  escrow.write(180);
  delay (500);
  escrow.write(85);
}

void deposit() {                                                                                    // Münzen in Kasse
  escrow.write(0);
  delay (500);
  escrow.write(85);
}

//void sendstatus () {                                                                                // Status per Telegramm senden
//  if (WiFi.status() == WL_CONNECTED) {
//    bot.sendMessage(CHAT_ID, statusMessage, "");
//  }
//}

void all_off () {                                                                                   // Vendinator abschalten
  deposit();
  delay(1000);
  Wire.beginTransmission(IOexpander);
  Wire.write(B01111111);
  Wire.endTransmission();
}

void coin_on () {                                                                                   // Münzprüfer anschalten
  Wire.beginTransmission(IOexpander);
  Wire.write(B10111111);
  Wire.endTransmission();
  delay(1000);
  coinnew = false;
  coinimpulse = 0;
  credit = 0;
}

void coin_off () {                                                                                  // Münzprüfer ausschalten
  Wire.beginTransmission(IOexpander);
  Wire.write(B11111111);
  Wire.endTransmission();
}

void readdata () {                                                                                  // Daten aus EEProm lesen
  EEPROM.get(0, slot_1);
  EEPROM.get(1, slot_2);
  EEPROM.get(2, slot_3);
  EEPROM.get(3, slot_4);
  EEPROM.get(4, slot_5);
  EEPROM.get(5, slot_6);
  EEPROM.get(6, cost_1);
  EEPROM.get(10, cost_2);
  EEPROM.get(14, cost_3);
  EEPROM.get(18, cost_4);
  EEPROM.get(22, cost_5);
  EEPROM.get(26, cost_6);
  EEPROM.get(30, cash);
}

void updateInventory(int choice) {                                                                 // Inventar aktualisieren
  switch (choice) {
    case 1:  slot_1 = 0; EEPROM.put(0, slot_1); break;                                             // Speichere den aktualisierten Wert in das EEPROM für Slot 1-6
    case 2:  slot_2 = 0; EEPROM.put(1, slot_2); break;
    case 3:  slot_3 = 0; EEPROM.put(2, slot_3); break;
    case 4:  slot_4 = 0; EEPROM.put(3, slot_4); break;
    case 5:  slot_5 = 0; EEPROM.put(4, slot_5); break;
    case 6:  slot_6 = 0; EEPROM.put(5, slot_6); break;
    default: break;                                                                                // Ungültige Choice-Nummer, wird beendet
  }
  EEPROM.put(30, cash);                                                                            // Kasseninhalt speichern
  EEPROM.commit();                                                                                 // Speicher die Änderungen im EEPROM
}

void printSlots(bool slot1, bool slot2, bool slot3, bool slot4, bool slot5, bool slot6) {          // Füllstand der Fächer für Ausgabe aufbereiten
  int slots[] = {slot1, slot2, slot3, slot4, slot5, slot6};
  bool firstPrinted = false;
  for (int i = 0; i < 6; i++) {
    if (slots[i] != 0) {
      if (firstPrinted) {
        lcd.print(" ");
      }
      lcd.print(i + 1);                                                                            // Index + 1 ergibt die Fachnummer
      firstPrinted = true;
    } else {
      if (firstPrinted) {
        lcd.print(" ");
      }
      lcd.print("-");                                                                              // "-" anzeigen, wenn das Fach leer ist
      firstPrinted = true;
    }
  }
}
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
void loop() {

  currentMillis = millis();                                                                        // millis in Variable schreiben

  if (digitalRead(lockpin) == HIGH && doorstate == 0) {                                            // Türen überprüfen
    lcd.setCursor(15, 0); lcd.print("TUER!");
    doorstate = 1;
  } else if (digitalRead(lockpin) == LOW && doorstate == 1) {
    lcd.setCursor(15, 0); lcd.print("     ");
    doorstate = 0;
    delay(500);
  }

  if (currentMillis - previousMillis >= maxtidle) {                                                // Idle Timer abgelaufen, abschalten
  //  statusMessage = "Vendinator wurde automatisch Abgeschaltet";
  //  sendstatus();
    lcd.clear();
    lcd.setCursor(0, 1); lcd.print("    Automatische    ");
    lcd.setCursor(0, 2); lcd.print("    Abschaltung     ");
    delay(1000);
    all_off();
    ESP.restart();
  }

  if (adminstate != 0 && digitalRead(lockpin) != HIGH) {                                           // Adminmodus, wenn adminpin = LOW

    char customKey = customKeypad.getKey();                                                        // Tastaturabfrage

    if (adminstate == 1) {
      if (customKey == '1') {
        adminstate = 2;                                                                            // Nächster Zustand: Fach auswählen Befüllen
        previousMillis = currentMillis;                                                            // Idle Timer für automatische Abschaltung zurücksetzen
        lcd.clear();
        lcd.setCursor(0,  0); lcd.print("     Adminmodus     ");
        lcd.setCursor(0,  1); lcd.print(" Befuellen / Leeren ");
        lcd.setCursor(0,  2); lcd.print("Fach auswaehlen  1-6");
      } else if (customKey == '2') {
        adminstate = 4;                                                                           // Nächster Zustand: Preis anpassen
        previousMillis = currentMillis;                                                           // Idle Timer für automatische Abschaltung zurücksetzen
        lcd.clear();
        lcd.setCursor(0,  0);  lcd.print("     Adminmodus     ");
        lcd.setCursor(0,  1); lcd.print("   Preis anpassen  ");
        lcd.setCursor(0,  2); lcd.print("Fach auswaehlen  1-6");
      } else if (customKey == '3') {
        adminstate = 6;                                                                           // Nächster Zustand: Kasse leeren
        previousMillis = currentMillis;                                                           // Idle Timer für automatische Abschaltung zurücksetzen
        lcd.clear();
        lcd.setCursor(0, 0);  lcd.print("     Adminmodus     ");
        lcd.setCursor(0,  1); lcd.print("Kasse : "); lcd.print(cash); lcd.print(" Euro");
        lcd.setCursor(0,  2); lcd.print("Abbruch -> A");
        lcd.setCursor(0,  3); lcd.print("Leeren  -> C");
      } else if (customKey == '4') {
        adminstate = 7;                                                                           // Nächster Zustand: Kasse leeren
        previousMillis = currentMillis;                                                           // Idle Timer für automatische Abschaltung zurücksetzen
        lcd.clear();
        lcd.setCursor(0,  0); lcd.print("1>"); lcd.print(slot_1); lcd.print(" "); lcd.print(cost_1);
        lcd.setCursor(10, 0); lcd.print("2>"); lcd.print(slot_2); lcd.print(" "); lcd.print(cost_2);
        lcd.setCursor(0,  1); lcd.print("3>"); lcd.print(slot_3); lcd.print(" "); lcd.print(cost_3);
        lcd.setCursor(10, 1); lcd.print("4>"); lcd.print(slot_4); lcd.print(" "); lcd.print(cost_4);
        lcd.setCursor(0,  2); lcd.print("5>"); lcd.print(slot_5); lcd.print(" "); lcd.print(cost_5);
        lcd.setCursor(10, 2); lcd.print("6>"); lcd.print(slot_6); lcd.print(" "); lcd.print(cost_6);
        lcd.setCursor(0,  3); lcd.print("Zurueck -> D");
      } else if (customKey == '5') {
        adminstate = 8;                                                                           // Nächster Zustand: Steuern
        previousMillis = currentMillis;                                                           // Idle Timer für automatische Abschaltung zurücksetzen
        controlmenu();
      } else if (customKey == '6') {                                                              // Restart
        lcd.clear();
        lcd.setCursor(0,  2); lcd.print(" Reboot  Vendinator ");
        delay(1000);
        ESP.restart();
      }
    } // Ende adminstate 1

    else if (adminstate == 2) {                                                                   // Fach auswählen Befüllen
      if (customKey >= '1' && customKey <= '6') {
        slotNum = atoi(&customKey);
        previousMillis = currentMillis;                                                           // Idle Timer für automatische Abschaltung zurücksetzen
        adminstate = 3;                                                                           // Nächster Zustand: Fach gefüllt, speichern und EEPROM aktualisieren
        lcd.clear();
        lcd.setCursor(0, 0);  lcd.print("     Adminmodus     ");
        lcd.setCursor(0,  1); lcd.print("Fach "); lcd.print(slotNum);
        lcd.setCursor(0,  2); lcd.print("Befuellen -> B");
        lcd.setCursor(0,  3); lcd.print("Entleeren -> C");
        openslot(slotNum);
      }
    } //Ende adminstate 2

    else if (adminstate == 3) {                                                                   // Fach gefüllt, speichern und EEPROM aktualisieren
      if (customKey == 'B') {
        previousMillis = currentMillis;                                                           // Idle Timer für automatische Abschaltung zurücksetzen
        switch (slotNum) {
          case 1: slot_1 = 1; EEPROM.put(0, slot_1); break;
          case 2: slot_2 = 1; EEPROM.put(1, slot_2); break;
          case 3: slot_3 = 1; EEPROM.put(2, slot_3); break;
          case 4: slot_4 = 1; EEPROM.put(3, slot_4); break;
          case 5: slot_5 = 1; EEPROM.put(4, slot_5); break;
          case 6: slot_6 = 1; EEPROM.put(5, slot_6); break;
        }
        EEPROM.commit();
        lcd.clear();
        lcd.setCursor(0,  1); lcd.print("  Neuer Fuellstand  ");
        lcd.setCursor(4,  2); printSlots(slot_1, slot_2, slot_3, slot_4, slot_5, slot_6);
        delay(1000);
        adminmenu();
        adminstate = 1; // Zurück zum Hauptmenü
      }
      if (customKey == 'C') {
        previousMillis = currentMillis;                                                           // Idle Timer für automatische Abschaltung zurücksetzen
        switch (slotNum) {
          case 1: slot_1 = 0; EEPROM.put(0, slot_1); break;
          case 2: slot_2 = 0; EEPROM.put(1, slot_2); break;
          case 3: slot_3 = 0; EEPROM.put(2, slot_3); break;
          case 4: slot_4 = 0; EEPROM.put(3, slot_4); break;
          case 5: slot_5 = 0; EEPROM.put(4, slot_5); break;
          case 6: slot_6 = 0; EEPROM.put(5, slot_6); break;
        }
        EEPROM.commit();
        lcd.clear();
        lcd.setCursor(0,  1); lcd.print("  Neuer Fuellstand  ");
        lcd.setCursor(4,  2); printSlots(slot_1, slot_2, slot_3, slot_4, slot_5, slot_6);
        delay(1000);
        adminmenu();
        adminstate = 1; // Zurück zum Hauptmenü
      }
    } //Ende adminstate 3

    else if (adminstate == 4) {                                                                   // Preis anpassen
      if (customKey >= '1' && customKey <= '6') {
        priceAdjustSlot = atoi(&customKey);
        adminstate = 5;                                                                           // Nächster Zustand: Preis eingeben
        previousMillis = currentMillis;                                                           // Idle Timer für automatische Abschaltung zurücksetzen
        lcd.clear();
        lcd.setCursor(0, 0);  lcd.print("     Adminmodus     ");
        lcd.setCursor(0,  1); lcd.print("Preise eingeben,");
        lcd.setCursor(0,  2); lcd.print("dann -> D ");
        lcd.setCursor(0,  3); lcd.print("Neuer Preis: ");
        priceStr = "";
      }
    } //Ende adminstate 4
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

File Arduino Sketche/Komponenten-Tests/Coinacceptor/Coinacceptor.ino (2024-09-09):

/* VENDINATOR
  Erste Versuche mit dem Münzprüfer

*/
int timeout = 710;                                       // So lange werden die Impulse gezählt
int timenow;                                             // Zeitvariable jetzt
float credit = 0;                                        // Hier wird das Eingeworfene Geld summiert
int coinimpulse = 0;                                     // Impulse des Münzprüfers
bool coinnew = false;                                    // Wird "true" wenn neue Münze eingeworfen

unsigned long coinstart = 0;                             // Zeitstop neue Münze Start
unsigned long cointimeout = 0;                           // Neue Münze start + timeout

static const uint8_t  coinpin = D5;                      // Pin für die Impulse des Münzprüfers

void ICACHE_RAM_ATTR isr() {                             // Interrupt funktion für die Münzprüfer Impulse
  timenow = millis();
  if (coinnew == false) {
    coinnew = true;
    coinstart = millis();
    cointimeout = coinstart + timeout;
  }
  if (coinnew == true && timenow < cointimeout) {
    timenow = millis();
    coinimpulse++;
  }
}

void setup() {
  Serial.begin(74880);                                   // Serielle Ausgabe starten
  pinMode(coinpin, INPUT);                               // Digitaler Port "coinpin" als Eingabe
  attachInterrupt(coinpin, isr, FALLING);                // Das Interrupt an den coinpin "hängen" / auf fallende Flanke reagieren
}

void loop() {
timenow = millis();
  if (coinnew == true && cointimeout < timenow)
  {
    Serial.printf("Gezählte Impulse %u \n", coinimpulse);
    switch (coinimpulse) {
    case 1: credit = credit + 200; break; 
    case 2: credit = credit + 100; break;  
    case 3: credit = credit + 50;  break; 
    case 4: credit = credit + 20;  break;
    case 5: credit = credit + 10;  break; 
    case 6: credit = credit + 5;   break;  
  }
  Serial.printf("credit %u \n", credit);
 
      coinnew = false;
      coinimpulse = 0;
  }
}  //Ende Loop
